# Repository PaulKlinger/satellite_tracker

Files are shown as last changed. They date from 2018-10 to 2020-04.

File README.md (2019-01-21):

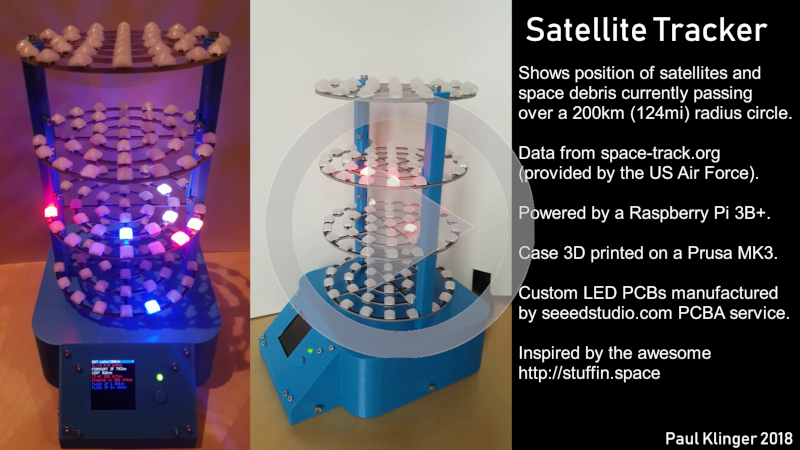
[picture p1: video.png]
(http://www.youtube.com/watch?v=Xof4bjcwHAY "Project video")


This is the code and hardware design for my
[Satellite tracker](https://www.reddit.com/r/space/comments/9py5qd/i_made_a_thingy_that_shows_satellites_and_space/).

The orbit_np.py file is a modified version of [pyorbital](https://github.com/pytroll/pyorbital)
(it calculates the orbits of all the satellites at the same time to increase performance).

Requires https://github.com/PaulKlinger/LIBtft144 and https://github.com/jgarff/rpi_ws281x + a bunch of libraries from PyPi.

The PCB design for the LED boards is in the PCBs/LED folder. I've reversed the VCC/GND connections on one side of the pcb
compared to my version to make assembly easier. Files for three additional PCBs connecting the various parts are in the
PCB/auxiliary folder (these are not strictly necessary, I just used protoboard for the first version).

The STLs and Fusion 360 source for the 3d printed parts are in the "3D printed parts" folder.
Note that the 3d printer files are for a slightly earlier version of the auxiliary PCBs, which still had some issues.
So the current ones probably don't fit exactly, e.g. the display cutout might be slightly offset.

I'd strongly recommend that anyone who builds this uses threaded rods through the pillars instead of the million screws
I used. (I just didn't have any rods and wanted to build it right away.)

The 3 PCBs in the PCBs/auxiliary folder include:
* One which splits the incoming micro usb power between the RaspberryPi and the LED boards.
Contains a micro usb port, a 1000uf capacitor, a right angle micro usb coord to connect to the Pi, and a connector
(LED strip type) to connect power to the led boards.
* A header board which plugs into the Pi. Contains a 2*20 pin header, a SN74AHCT125N level shifter,
and a 4 pin and 10 pin "JST 1.25mm" connector (that's what they are called on aliexpress at least).
* And an interface board with a standard (6x6mm) push button, a 470 ohm resistor, a 3mm LED,
and the 1.44" tft (with ST7735 driver chip)

These 3 PCBs are combined onto one ~10*10cm panel. Many PCB manufacturers charge extra for panelized designs but
[dirtypcbs](https://dirtypcbs.com) doesn't.

The designs here fix some errors of the ones that I ordered. Assembled mine look like this:
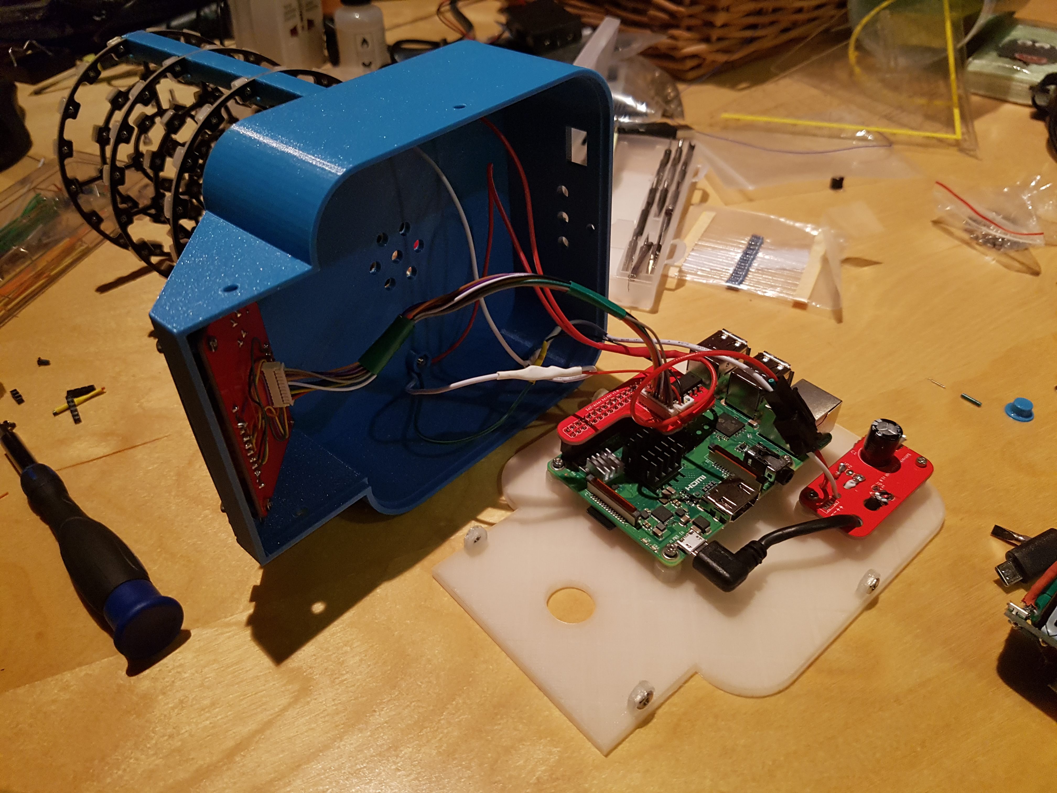
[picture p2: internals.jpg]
Sattracker internals


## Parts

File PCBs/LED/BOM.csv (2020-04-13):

Designator | Manufacturer Part Number | Quantity
C1,C2,C3,C4,C5,C6,C7,C8,C9,C10,C11,C12,C13,C14,C15,C16,C17,C18,C19,C20,C21,C22,C23,C24,C25,C26,C27,C28,C29,C30,C31,C32,C33,C34,C35,C36,C37 | CC0805KRX7R9BB104 | 37
L | WS2812B | 37

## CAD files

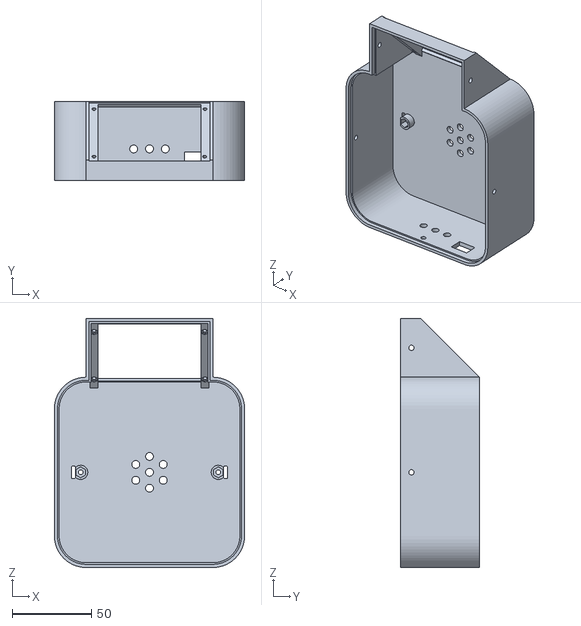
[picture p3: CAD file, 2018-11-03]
3D printed parts/case.stl
120.0 x 50.0 x 157.0

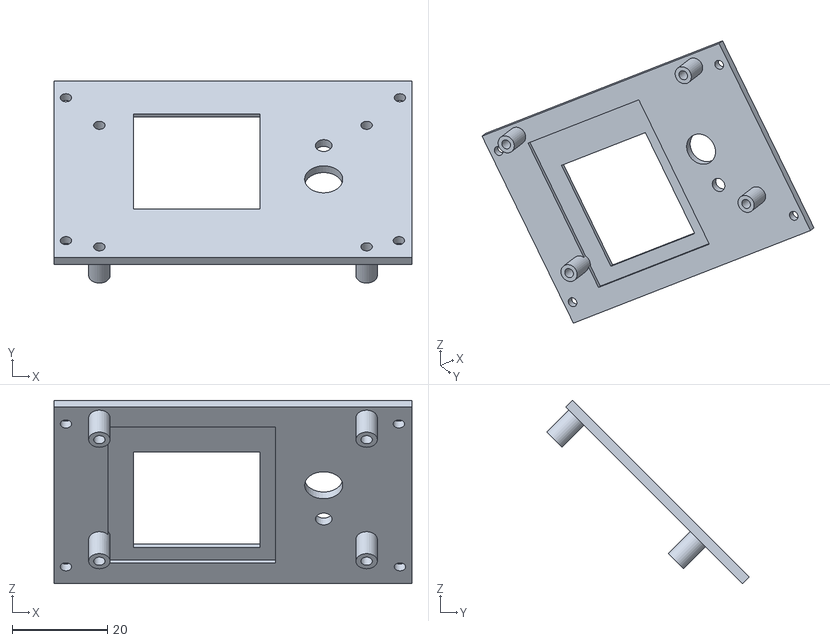
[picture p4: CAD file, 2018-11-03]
3D printed parts/interface plate.stl
75.0 x 42.4 x 38.4

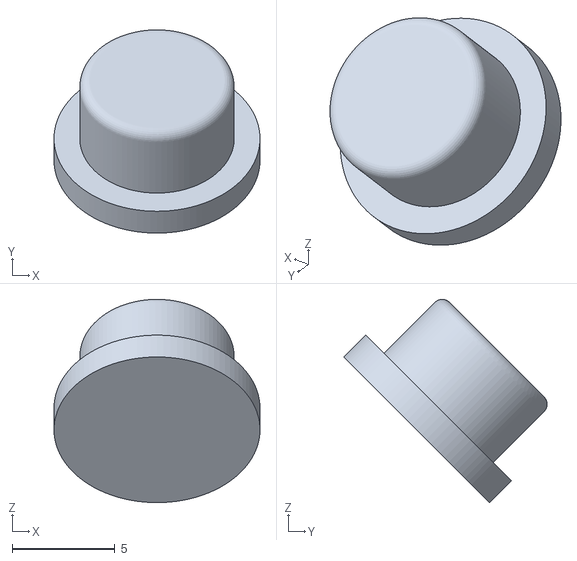
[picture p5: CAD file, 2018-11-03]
3D printed parts/Button.stl
10.0 x 9.87 x 9.87

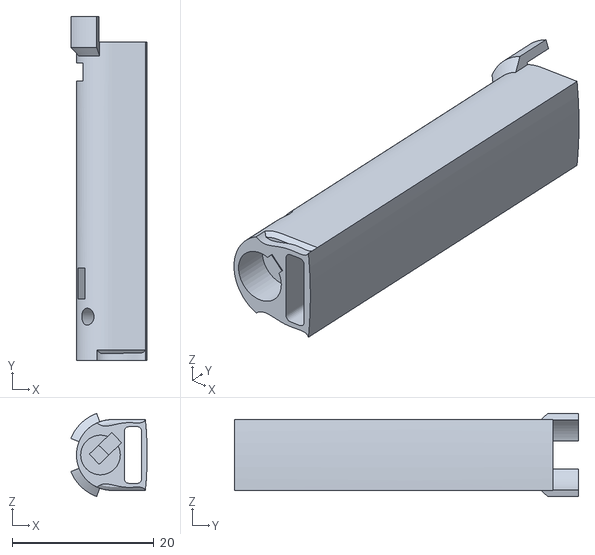
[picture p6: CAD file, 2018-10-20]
3D printed parts/top_pillar.stl
10.8 x 48.6 x 11.7

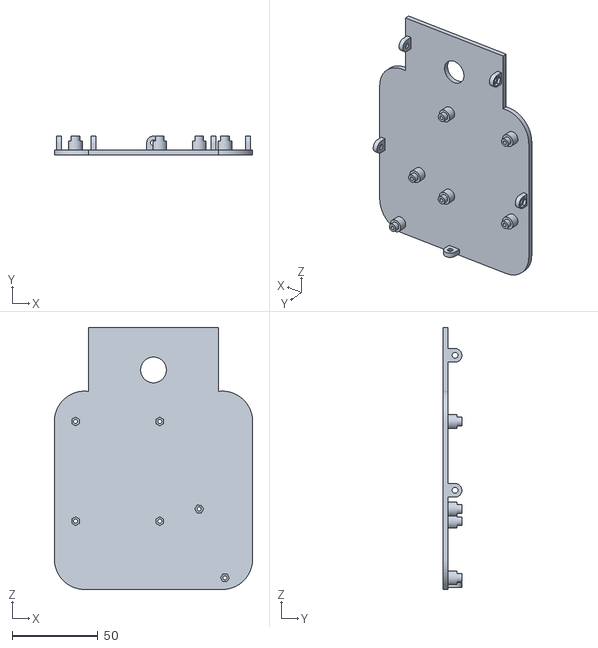
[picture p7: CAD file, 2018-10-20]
3D printed parts/bottom.stl
115.4 x 11.0 x 152.4

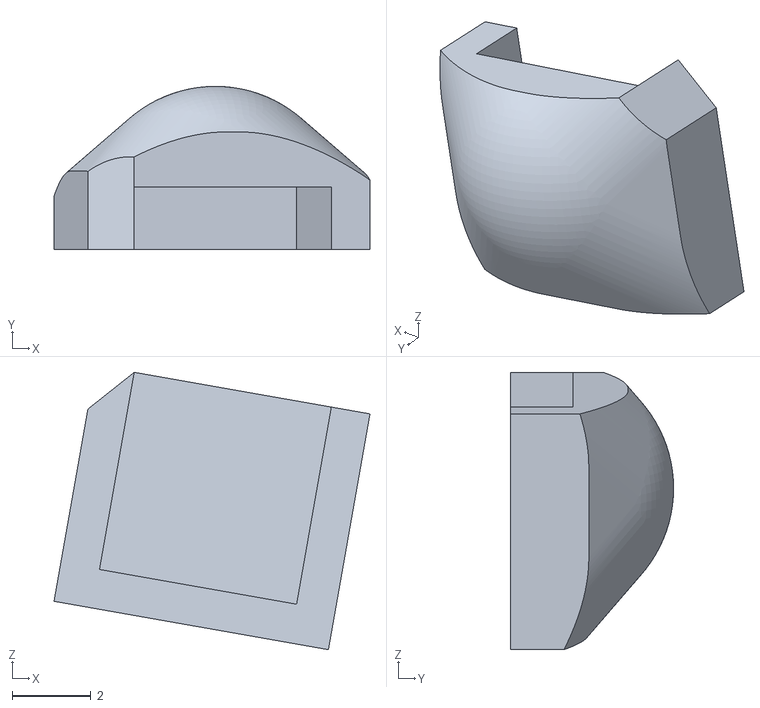
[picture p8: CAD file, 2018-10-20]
3D printed parts/diffuser_round_right.stl
8.05 x 4.16 x 7.07

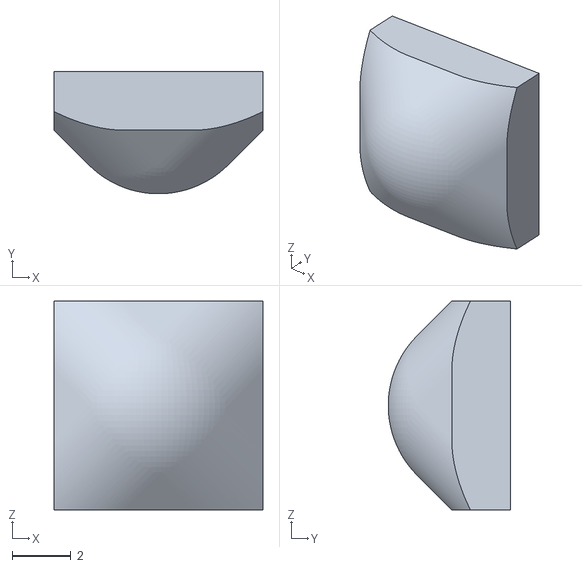
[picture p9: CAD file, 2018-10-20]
3D printed parts/diffuser_round.stl
7.10 x 4.16 x 7.10

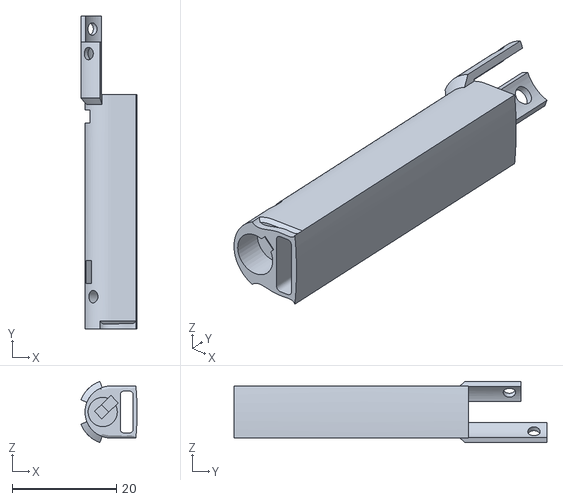
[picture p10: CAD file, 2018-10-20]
3D printed parts/middle_pillar.stl
10.8 x 60.0 x 11.7

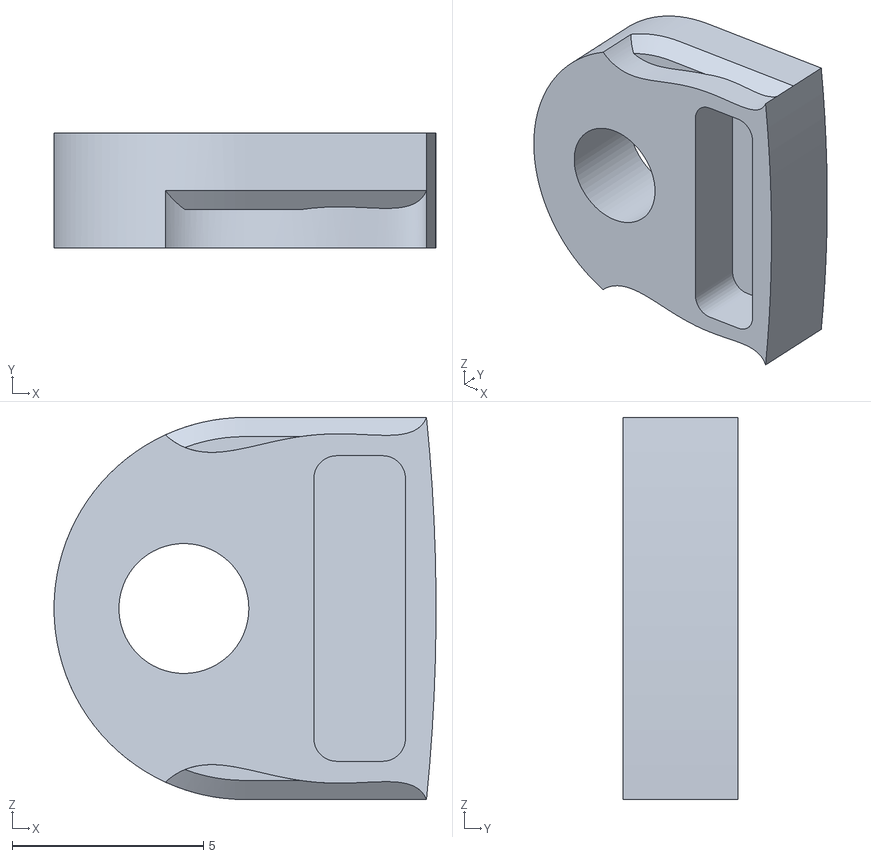
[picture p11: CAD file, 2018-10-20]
3D printed parts/top_cover.stl
10.00 x 3.00 x 10.00

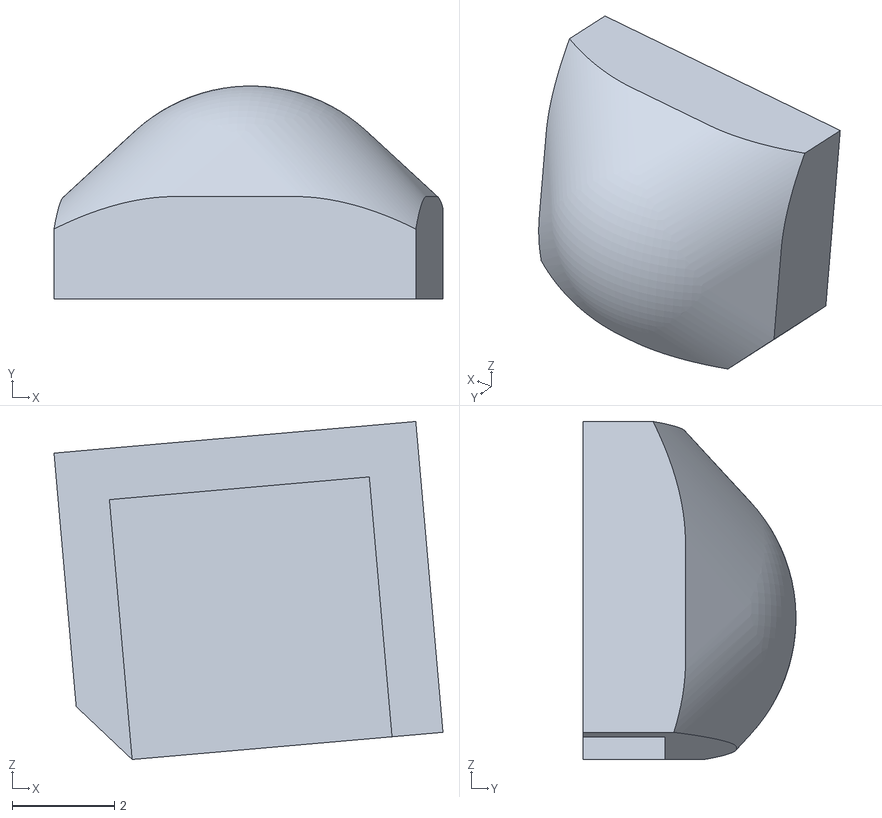
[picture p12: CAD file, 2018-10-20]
3D printed parts/diffuser_round_left.stl
7.60 x 4.16 x 6.61

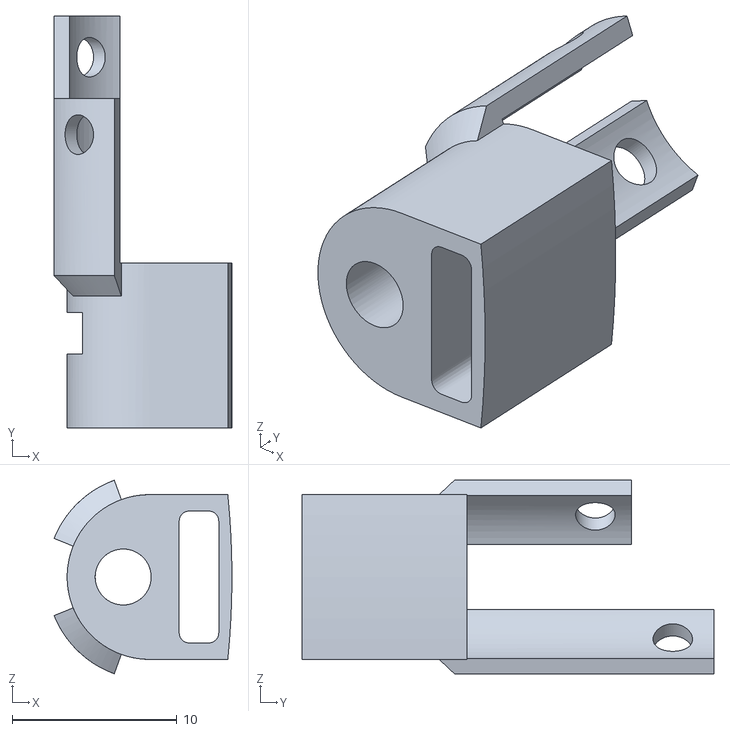
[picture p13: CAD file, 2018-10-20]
3D printed parts/bottom_pillar.stl
10.8 x 25.0 x 11.7

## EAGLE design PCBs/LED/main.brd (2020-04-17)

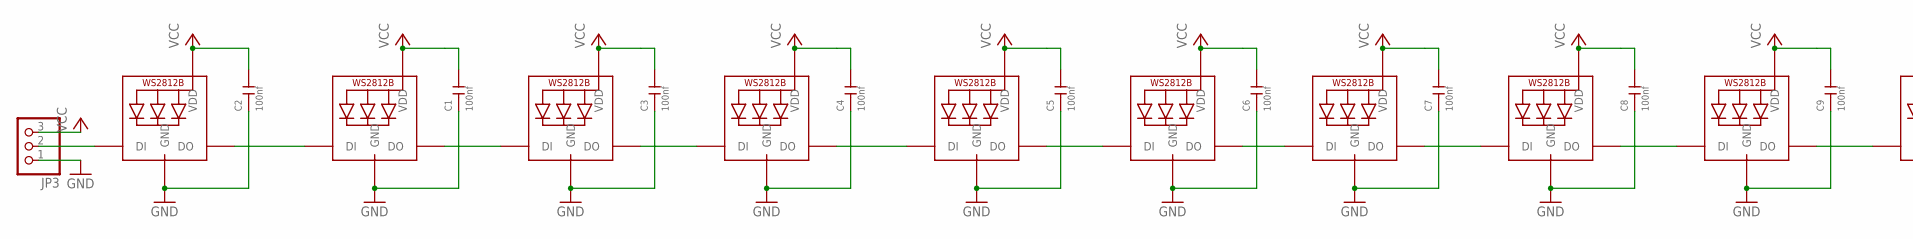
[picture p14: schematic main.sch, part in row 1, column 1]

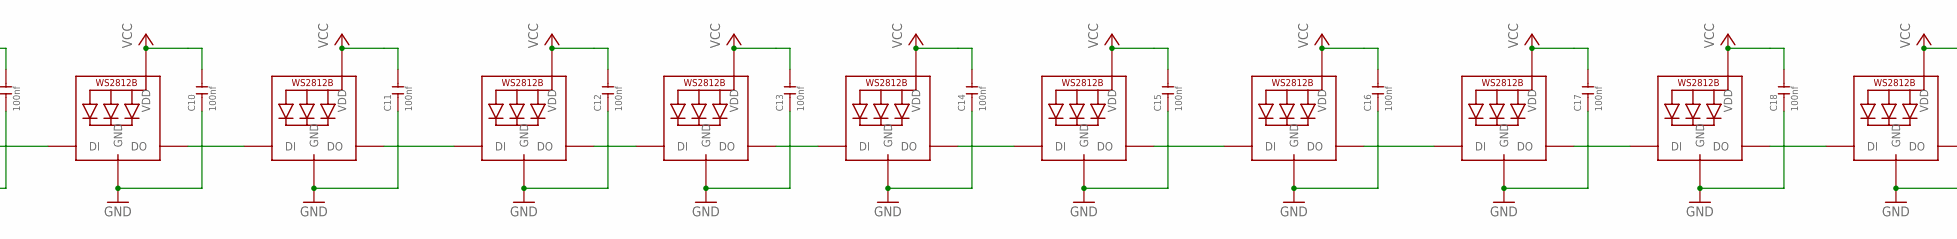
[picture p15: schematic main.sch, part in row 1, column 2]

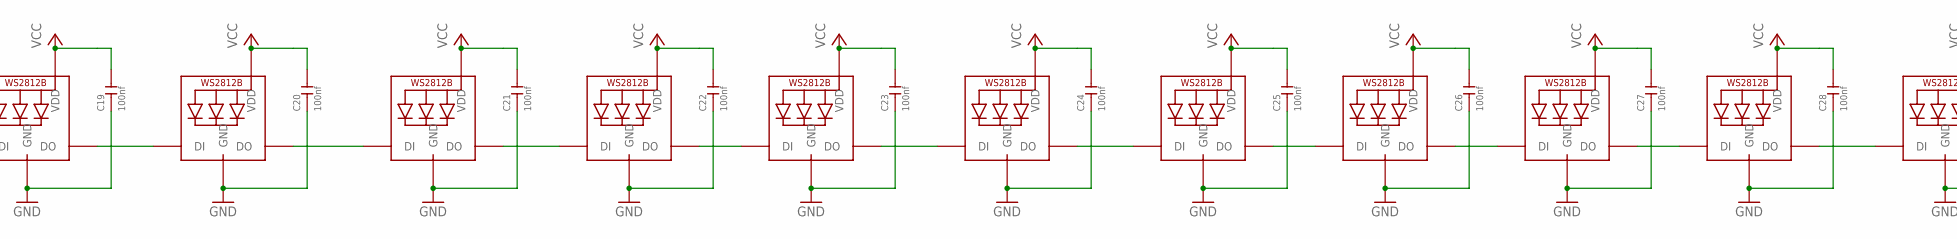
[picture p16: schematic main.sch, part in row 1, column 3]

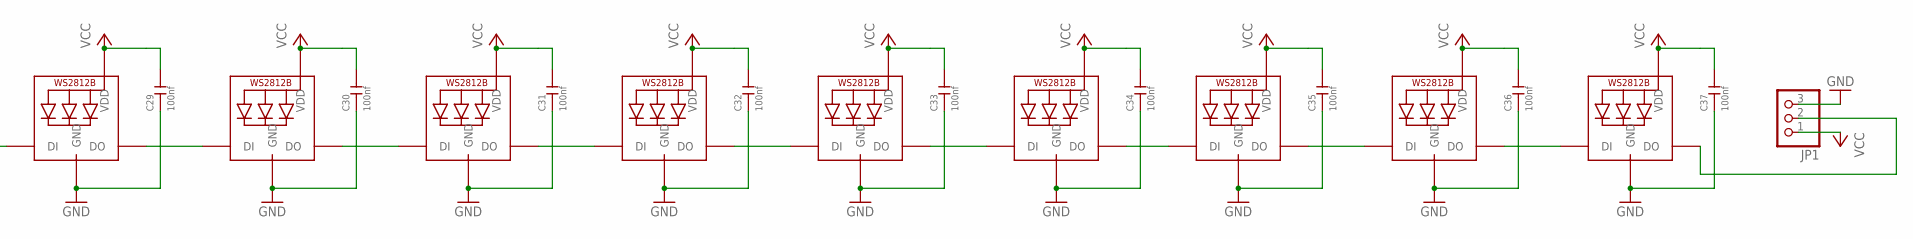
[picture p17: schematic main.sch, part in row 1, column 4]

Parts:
C1, C2, C3, C4, C5, C6, C7, C8, C9, C10, C11, C12, C13, C14, C15, C16, C17, C18, C19, C20, C21, C22, C23, C24, C25, C26, C27, C28, C29, C30, C31, C32, C33, C34, C35, C36, C37: 100nf; C0805
JP1, JP3: PINHD-1X3; 1X03
L: WS2812B5050; WS2812B
LED1, LED3, LED4, LED5, LED6, LED7, LED8, LED9, LED10, LED11, LED12, LED13, LED14, LED15, LED16, LED17, LED18, LED19, LED20, LED21, LED22, LED23, LED24, LED25, LED26, LED27, LED28, LED29, LED30, LED31, LED32, LED33, LED34, LED35, LED36, LED37: WS2812B5050; WS2812B

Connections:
GND: C1.1, C2.1, C3.1, C4.1, C5.1, C6.1, C7.1, C8.1, C9.1, C10.1, C11.1, C12.1, C13.1, C14.1, C15.1, C16.1, C17.1, C18.1, C19.1, C20.1, C21.1, C22.1, C23.1, C24.1, C25.1, C26.1, C27.1, C28.1, C29.1, C30.1, C31.1, C32.1, C33.1, C34.1, C35.1, C36.1, C37.1, JP1.3, JP3.1, L.3-GND (GND), LED1.3-GND (GND), LED3.3-GND (GND), LED4.3-GND (GND), LED5.3-GND (GND), LED6.3-GND (GND), LED7.3-GND (GND), LED8.3-GND (GND), LED9.3-GND (GND), LED10.3-GND (GND), LED11.3-GND (GND), LED12.3-GND (GND), LED13.3-GND (GND), LED14.3-GND (GND), LED15.3-GND (GND), LED16.3-GND (GND), LED17.3-GND (GND), LED18.3-GND (GND), LED19.3-GND (GND), LED20.3-GND (GND), LED21.3-GND (GND), LED22.3-GND (GND), LED23.3-GND (GND), LED24.3-GND (GND), LED25.3-GND (GND), LED26.3-GND (GND), LED27.3-GND (GND), LED28.3-GND (GND), LED29.3-GND (GND), LED30.3-GND (GND), LED31.3-GND (GND), LED32.3-GND (GND), LED33.3-GND (GND), LED34.3-GND (GND), LED35.3-GND (GND), LED36.3-GND (GND), LED37.3-GND (GND)
unnamed: L.2-DOUT (DO), LED1.4-DIN (DI)
unnamed: LED1.2-DOUT (DO), LED3.4-DIN (DI)
unnamed: LED3.2-DOUT (DO), LED4.4-DIN (DI)
unnamed: LED4.2-DOUT (DO), LED5.4-DIN (DI)
unnamed: LED5.2-DOUT (DO), LED6.4-DIN (DI)
unnamed: LED6.2-DOUT (DO), LED7.4-DIN (DI)
unnamed: LED7.2-DOUT (DO), LED8.4-DIN (DI)
unnamed: LED8.2-DOUT (DO), LED9.4-DIN (DI)
unnamed: LED9.2-DOUT (DO), LED10.4-DIN (DI)
unnamed: LED10.2-DOUT (DO), LED11.4-DIN (DI)
unnamed: LED11.2-DOUT (DO), LED12.4-DIN (DI)
unnamed: LED12.2-DOUT (DO), LED13.4-DIN (DI)
unnamed: LED13.2-DOUT (DO), LED14.4-DIN (DI)
unnamed: LED14.2-DOUT (DO), LED15.4-DIN (DI)
unnamed: LED15.2-DOUT (DO), LED16.4-DIN (DI)
unnamed: LED16.2-DOUT (DO), LED17.4-DIN (DI)
unnamed: LED17.2-DOUT (DO), LED18.4-DIN (DI)
unnamed: LED18.2-DOUT (DO), LED19.4-DIN (DI)
unnamed: LED19.2-DOUT (DO), LED20.4-DIN (DI)
unnamed: LED20.2-DOUT (DO), LED21.4-DIN (DI)
unnamed: LED21.2-DOUT (DO), LED22.4-DIN (DI)
unnamed: LED22.2-DOUT (DO), LED23.4-DIN (DI)
unnamed: LED23.2-DOUT (DO), LED24.4-DIN (DI)
unnamed: LED24.2-DOUT (DO), LED25.4-DIN (DI)
unnamed: LED25.2-DOUT (DO), LED26.4-DIN (DI)
unnamed: LED26.2-DOUT (DO), LED27.4-DIN (DI)
unnamed: LED27.2-DOUT (DO), LED28.4-DIN (DI)
unnamed: LED28.2-DOUT (DO), LED29.4-DIN (DI)
unnamed: LED29.2-DOUT (DO), LED30.4-DIN (DI)
unnamed: LED30.2-DOUT (DO), LED31.4-DIN (DI)
unnamed: LED31.2-DOUT (DO), LED32.4-DIN (DI)
unnamed: LED32.2-DOUT (DO), LED33.4-DIN (DI)
unnamed: LED33.2-DOUT (DO), LED34.4-DIN (DI)
unnamed: LED34.2-DOUT (DO), LED35.4-DIN (DI)
unnamed: LED35.2-DOUT (DO), LED36.4-DIN (DI)
unnamed: LED36.2-DOUT (DO), LED37.4-DIN (DI)
unnamed: JP3.2, L.4-DIN (DI)
unnamed: JP1.2, LED37.2-DOUT (DO)
VCC: C1.2, C2.2, C3.2, C4.2, C5.2, C6.2, C7.2, C8.2, C9.2, C10.2, C11.2, C12.2, C13.2, C14.2, C15.2, C16.2, C17.2, C18.2, C19.2, C20.2, C21.2, C22.2, C23.2, C24.2, C25.2, C26.2, C27.2, C28.2, C29.2, C30.2, C31.2, C32.2, C33.2, C34.2, C35.2, C36.2, C37.2, JP1.1, JP3.3, L.1-VDD (VDD), LED1.1-VDD (VDD), LED3.1-VDD (VDD), LED4.1-VDD (VDD), LED5.1-VDD (VDD), LED6.1-VDD (VDD), LED7.1-VDD (VDD), LED8.1-VDD (VDD), LED9.1-VDD (VDD), LED10.1-VDD (VDD), LED11.1-VDD (VDD), LED12.1-VDD (VDD), LED13.1-VDD (VDD), LED14.1-VDD (VDD), LED15.1-VDD (VDD), LED16.1-VDD (VDD), LED17.1-VDD (VDD), LED18.1-VDD (VDD), LED19.1-VDD (VDD), LED20.1-VDD (VDD), LED21.1-VDD (VDD), LED22.1-VDD (VDD), LED23.1-VDD (VDD), LED24.1-VDD (VDD), LED25.1-VDD (VDD), LED26.1-VDD (VDD), LED27.1-VDD (VDD), LED28.1-VDD (VDD), LED29.1-VDD (VDD), LED30.1-VDD (VDD), LED31.1-VDD (VDD), LED32.1-VDD (VDD), LED33.1-VDD (VDD), LED34.1-VDD (VDD), LED35.1-VDD (VDD), LED36.1-VDD (VDD), LED37.1-VDD (VDD)

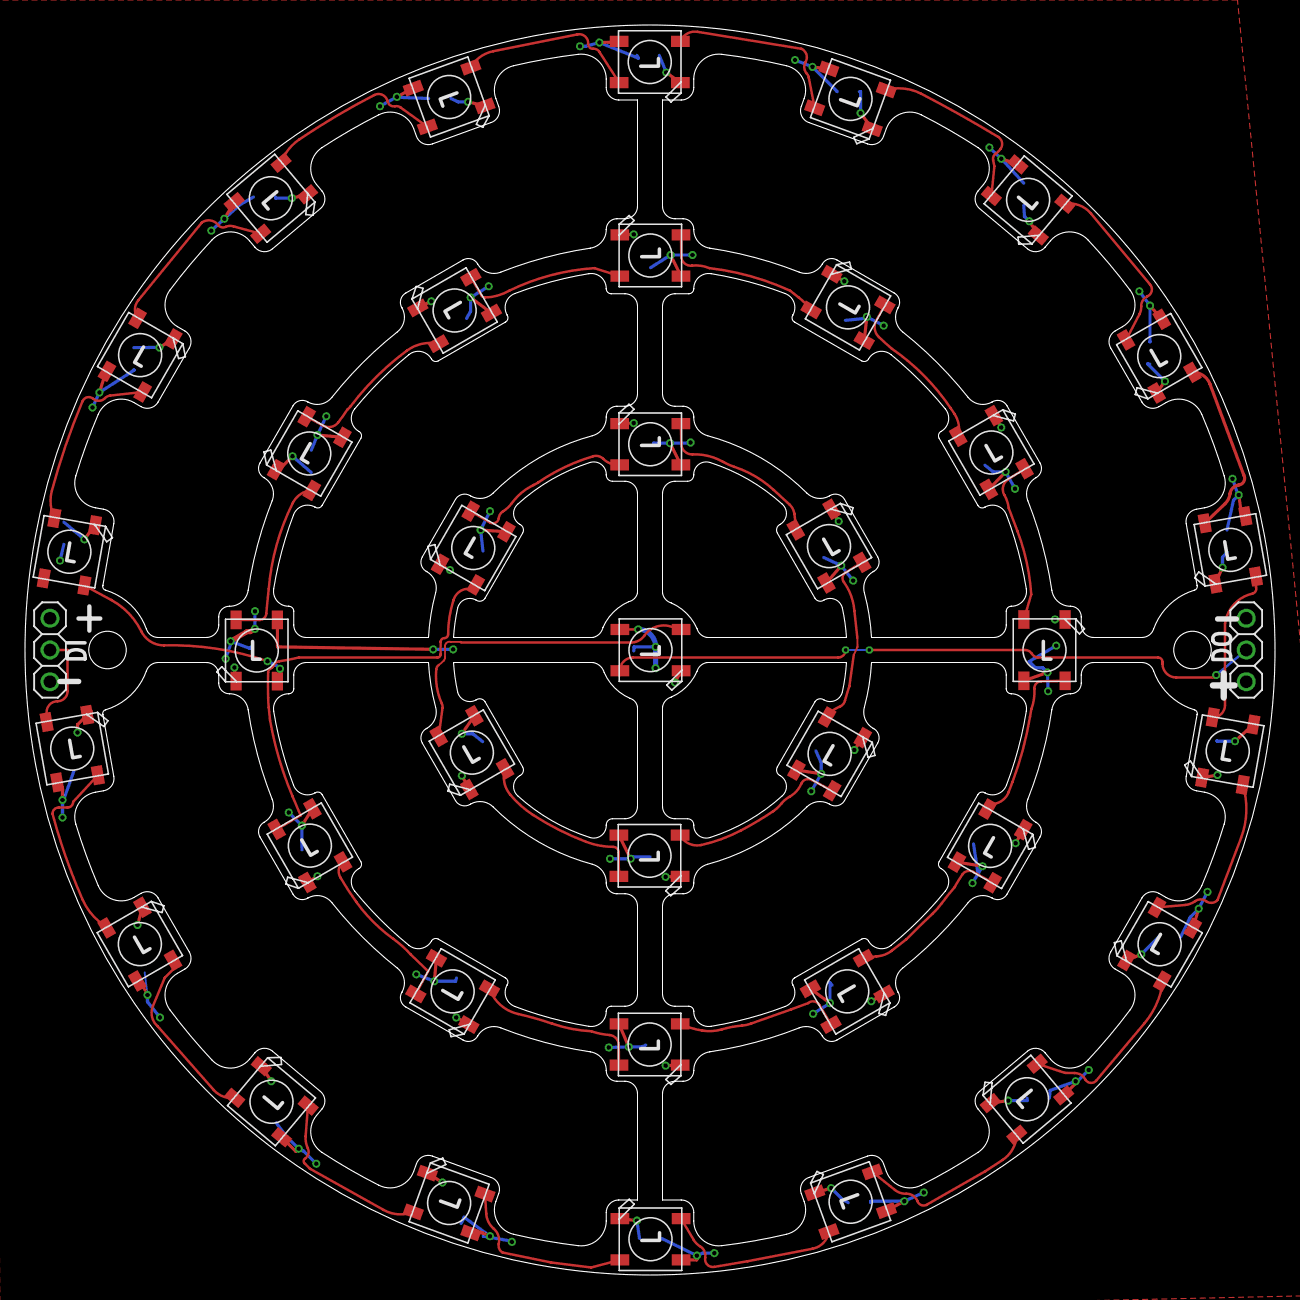
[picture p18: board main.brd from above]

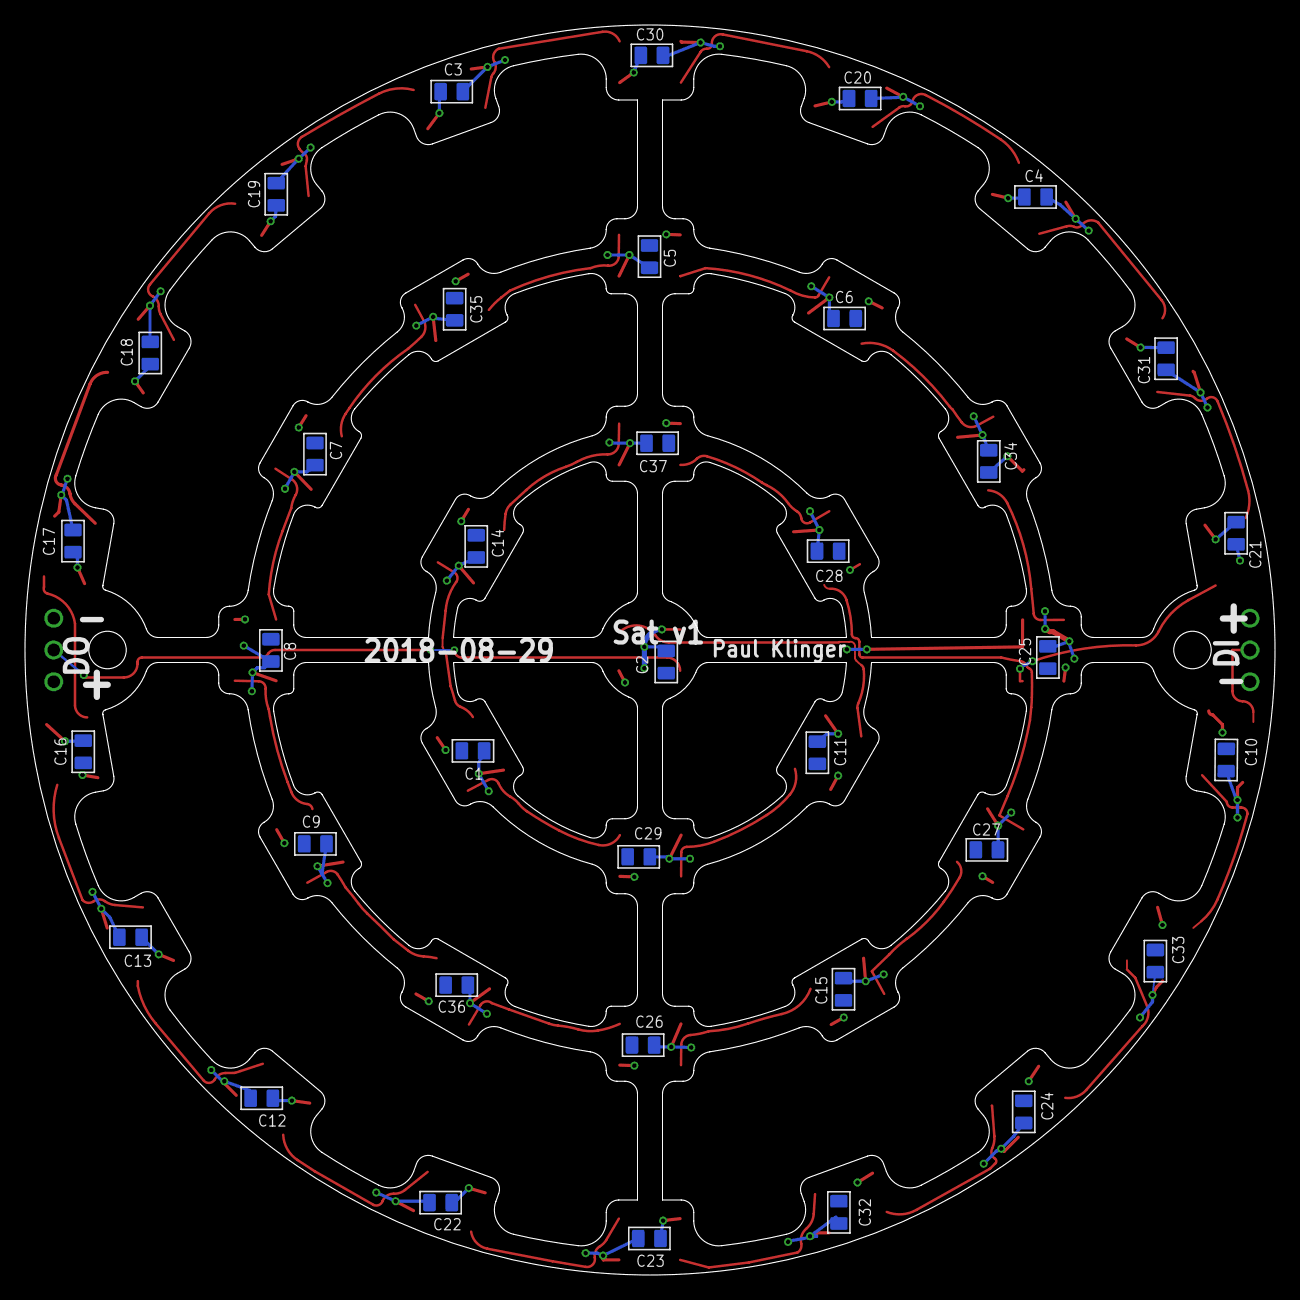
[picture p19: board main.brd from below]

Board: 2 copper layers, 100.0 x 100.0 mm, 76 parts (37 on the bottom side), 40 nets.

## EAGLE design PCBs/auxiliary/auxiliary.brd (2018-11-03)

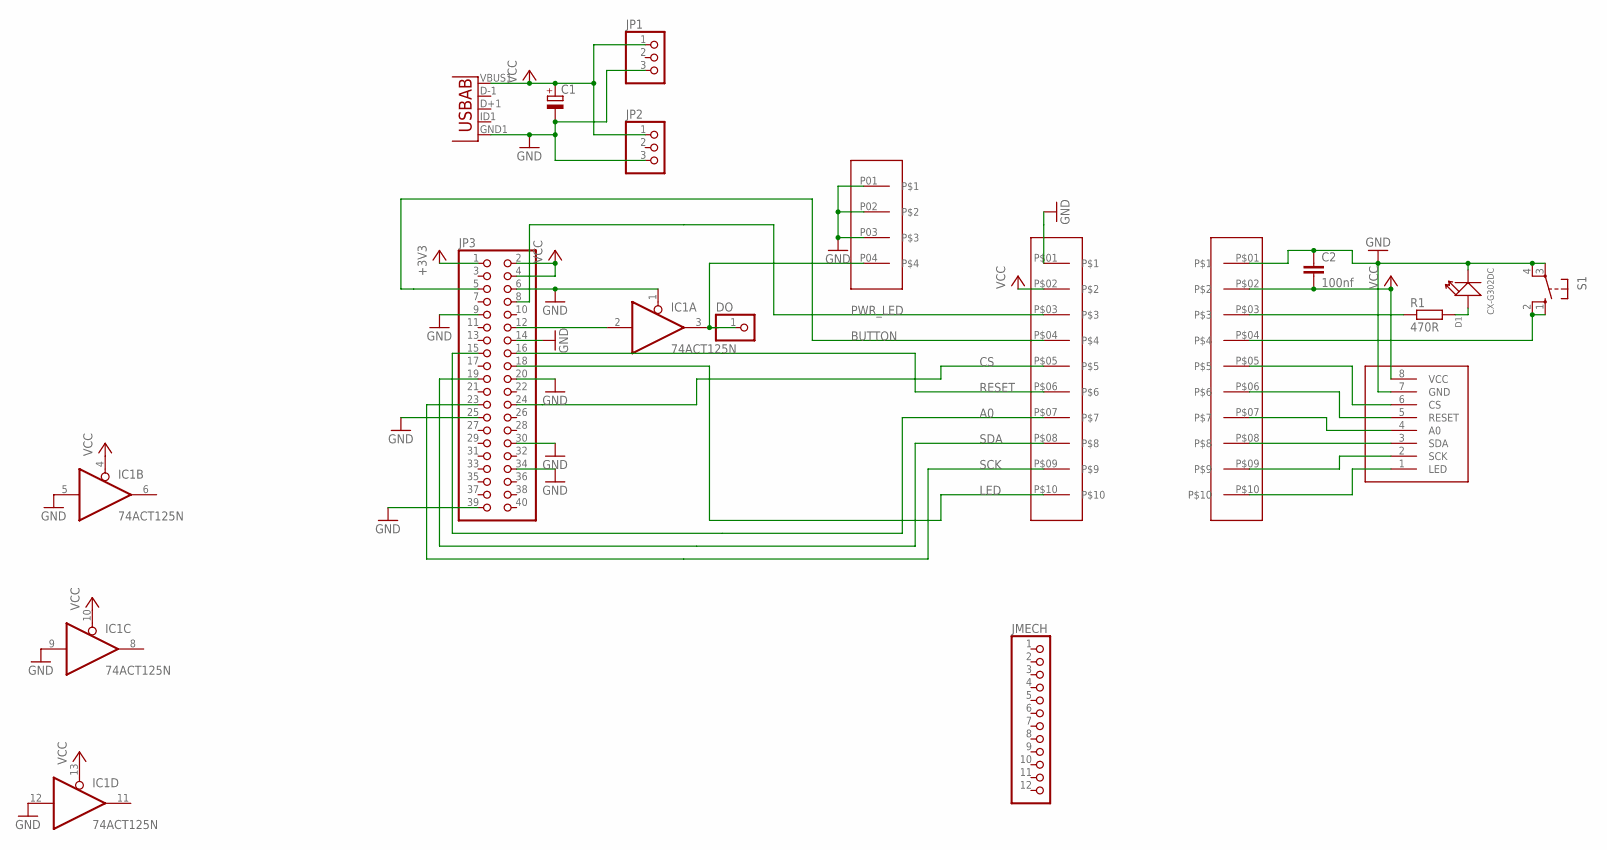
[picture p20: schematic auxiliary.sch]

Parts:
C1: CPOL-EUE5-10.5; E5-10,5
C2: 100nf; C025-030X050
D1: CX-G302DC; LED2-2.54-D3.0MM
DO: PINHD-1X1; 1X01
IC1: 74ACT125N; DIL14
J1, J2: JST1.25_10PIN
JMECH: PINHD-1X12; 1X12
JP1, JP2: PINHD-1X3; 1X03
JP3: PINHD-2X20; 2X20
R1: 470R; 0207/7
S1: 10-XX; B3F-10XX
U1: USB-THROUGH; USB-MICRO-THROUGH
U$2: SPI_TFT_1.44"
U$3: JST1.25_4PIN

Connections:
+3V3: JP3.1
A0: J1.P$07, JP3.15
BUTTON: J1.P$04, JP3.5
CS: J1.P$05, JP3.24
GND: C1.-, C2.1, D1.K (-), IC1.1 (OE), IC1.5 (I), IC1.7 (GND), IC1.9 (I), IC1.12 (I), J1.P$01, J2.P$01, JP1.3, JP2.3, JP3.6, JP3.9, JP3.14, JP3.20, JP3.25, JP3.30, JP3.34, JP3.39, S1.3, S1.4 (P1), U1.GND1 (GND), U$2.7 (GND), U$3.P01, U$3.P02, U$3.P03
LED: J1.P$10, JP3.18
unnamed: D1.A (+), R1.2
unnamed: DO.1, IC1.3 (O), U$3.P04
unnamed: IC1.2 (I), JP3.12
unnamed: J2.P$05, U$2.6 (CS)
unnamed: J2.P$06, U$2.5 (RESET)
unnamed: J2.P$07, U$2.4 (A0)
unnamed: J2.P$08, U$2.3 (SDA)
unnamed: J2.P$09, U$2.2 (SCK)
unnamed: J2.P$03, R1.1
unnamed: J2.P$10, U$2.1 (LED)
unnamed: J2.P$04, S1.1 (S), S1.2 (S1)
PWR_LED: J1.P$03, JP3.8
RESET: J1.P$06, JP3.16
SCK: J1.P$09, JP3.23
SDA: J1.P$08, JP3.19
VCC: C1.+, C2.2, IC1.4 (OE), IC1.10 (OE), IC1.13 (OE), IC1.14 (VCC), J1.P$02, J2.P$02, JP1.1, JP2.1, JP3.2, JP3.4, U1.VBUS1 (VBUS), U$2.8 (VCC)

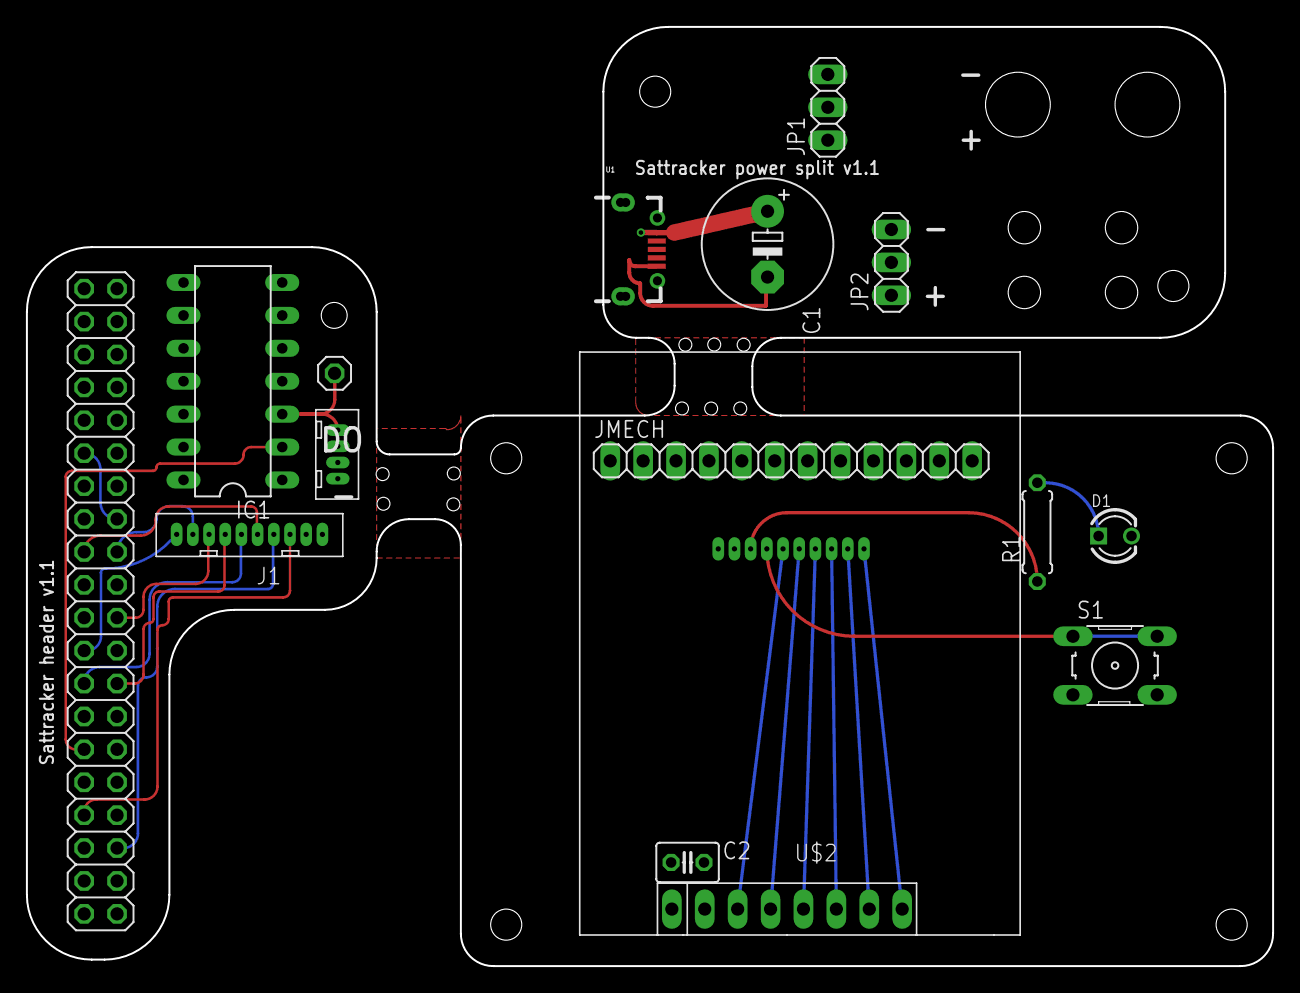
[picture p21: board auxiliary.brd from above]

Board: 2 copper layers, 96.2 x 72.5 mm, 16 parts (1 on the bottom side), 21 nets.

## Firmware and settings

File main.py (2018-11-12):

from datetime import datetime, timedelta
from time import time, sleep
import itertools
import multiprocessing as mp
import subprocess
import queue
from collections import defaultdict
import os
import os.path
from typing import List, Tuple, Optional

from subprocess import check_call

from geopy import distance
import neopixel
from gpiozero import Button
import RPi.GPIO as GPIO
from LIBtft144.lib_tft144 import TFT144
import spidev

from orbit_np import Orbitals
from demo import chase_loop, random_loop, rings_loop, spinning_loop, alternate_loop, half_loop
from constants import *


class NearbySatFinder(object):
    def __init__(self, tlefile: str, loc: Pos):
        self.loc = loc
        self.longfactor = np.cos(np.deg2rad(loc.lat))
        self.tles = []
        satnames = []

        with open(tlefile) as f:
            n = 0
            while True:
                n += 1
                satname = f.readline().strip()
                if not satname:
                    # there should be exactly one empty line at the end of the TLE file
                    # check if we are at the end of the file after reading it
                    if f.read(1) != "":  # at the end file.read returns ""
                        # if we are not at the end, something is wrong -> abort
                        raise ValueError("Unexpected empty line in TLE file!")

                    print("Loaded {} sats.".format(n))
                    break
                line1 = f.readline().strip()
                line2 = f.readline().strip()
                if line1 and line2:
                    self.tles.append((line1, line2))
                    satnames.append(satname)

        self.satnames = np.array(satnames)

        self.last_query_t = -1000

        self.filtered_errors = False
        self.create_orbitals()

    def create_orbitals(self):
        print("creating orbitals")
        self.orbs = Orbitals(self.tles)

    def nearby_now(self) -> List[Tuple[str, Pos, float]]:
        now = datetime.utcnow()

        t1 = time()
        self.last_query_t = t1

        lons, lats, alts, errors = self.orbs.get_lonlatalt(now)
        t2 = time()
        rough_near = np.logical_and(np.abs(lats - self.loc.lat) < 3, np.abs(lons - self.loc.long) < 3)
        valid_satpos = list(
            zip(self.satnames[~errors][rough_near], lats[rough_near], lons[rough_near], alts[rough_near]))
        nearby = [(name, Pos(lat=lat, long=lon), alt) for name, lat, lon, alt in valid_satpos if
                  distance.distance(self.loc, (lat, lon)).km < 200]
        t3 = time()
        print("loc:{:.2f}s dist: {:.2f}s tot: {:.2f}s, sats: {:02d}".format(t2 - t1, t3 - t2, t3 - t1, len(nearby)))

        if not self.filtered_errors:
            print("filtering errors")
            self.satnames = self.satnames[~errors]
            self.tles = itertools.compress(self.tles, ~errors)
            self.create_orbitals()
            self.filtered_errors = True
        return nearby


class LedArray(object):
    def __init__(self, ring_radii, ring_ledns, ring_startangles, ring_dirs, eq_radius, pos: Pos,
                 upper_levels_alt_lower_boundaries):
        self.eq_radius = eq_radius  # equivalent real radius in km
        self.pos = pos
        self.upper_levels_alt_lower_boundaries = upper_levels_alt_lower_boundaries
        self.level_ledn = np.sum(ring_ledns)

        self.longfactor = np.cos(np.deg2rad(self.pos.lat))
        degreelength = 111  # km
        self.levels_led_poss = []
        distance_factor = eq_radius / np.max(ring_radii)
        for level in range(len(upper_levels_alt_lower_boundaries) + 1):
            led_poss = []
            for ringr, ledn, startangle, direction in zip(ring_radii, ring_ledns, ring_startangles, ring_dirs):
                startangle += (level % 2) * np.pi  # upper levels are rotated 180 degree (to connect do/di)
                anglestep = 2 * np.pi / ledn
                led_poss += [
                    Pos(lat=pos.lat - distance_factor * ringr * np.cos(
                        startangle + i * anglestep * direction) / degreelength,
                        long=pos.long + distance_factor * ringr * np.sin(
                            startangle + i * anglestep * direction) / degreelength / self.longfactor
                        ) for i in range(ledn)]
            self.levels_led_poss.append(led_poss)

    def _level_from_alt(self, alt: float) -> int:
        i = 0
        for alt_boundary in self.upper_levels_alt_lower_boundaries:
            if alt < alt_boundary:
                break
            i += 1
        return i

    def closest_led(self, pos: Pos, alt: float) -> Tuple[Pos, int, float]:
        level = self._level_from_alt(alt)
        closest_led_index = None
        closest_led_distance = (2 * self.eq_radius) ** 2
        for i, ledpos in enumerate(self.levels_led_poss[level]):
            # naive distance calculation, accurate enough for the inter-led distances
            d = ((ledpos.long - pos.long) * self.longfactor) ** 2 + (ledpos.lat - pos.lat) ** 2
            if d < closest_led_distance:
                closest_led_distance = d
                closest_led_index = i

        closest_led_pos = self.levels_led_poss[level][closest_led_index]
        closest_led_index += level * self.level_ledn
        return closest_led_pos, closest_led_index, closest_led_distance


def led_array_from_constants():
    # convenience function
    return LedArray(ring_radii=RING_RADII, ring_ledns=RING_LEDNS, ring_startangles=RING_STARTANGLES,
                    ring_dirs=RING_DIRECTIONS, eq_radius=EQUIV_RADIUS, pos=CENTER_LOCATION,
                    upper_levels_alt_lower_boundaries=UPPER_LEVELS_ALT_LOWER_BOUNDARIES)


def color_priority_from_name(name: str) -> Tuple[RGB, int, RGB]:
    for c, tftc_prio_ledc in CLASS_COLORS_PRIORITIES:
        if any(s in name for s in c):
            return tftc_prio_ledc


def run_demo(strip: neopixel.Adafruit_NeoPixel, led_queue: mp.Queue):
    for demo in (chase_loop, spinning_loop, rings_loop, random_loop):
        print("demo: {}".format(demo))
        p = mp.Process(target=demo, kwargs={"strip": strip, })
        p.start()
        sleep(5)  # show each demo for 5s
        while True:
            # get messages, ignore satellite updates that might still be in the queue
            try:
                m = led_queue.get_nowait()
                if m == "BUTTON":  # if the button is pressed we stay in the demo
                    while True:
                        m = led_queue.get()
                        if m == "BUTTON":  # if the button is pressed again we exit
                            p.terminate()
                            return
            except queue.Empty:
                # if there was no button press move on to the next demo
                p.terminate()
                break


def led_strip_from_constants():
    return neopixel.Adafruit_NeoPixel(LED_COUNT, LED_PIN, LED_FREQ_HZ, LED_DMA,
                                      LED_INVERT, LED_BRIGHTNESS, LED_CHANNEL,
                                      strip_type=neopixel.ws.WS2811_STRIP_GRB)


def led_control(led_queue: mp.Queue, demo_mode: mp.Lock):
    strip = led_strip_from_constants()

    # Intialize the library (must be called once before other functions).
    strip.begin()

    def set_all(strip, color):
        for i in range(strip.numPixels()):
            strip.setPixelColor(i, color)
        strip.show()

    set_all(strip, neopixel.Color(0, 0, 0))

    current = defaultdict(lambda: RGB(0, 0, 0))  # TODO: add variable type hints once Raspbian includes Python >=3.6
    target = defaultdict(lambda: RGB(0, 0, 0))
    step = defaultdict(lambda: RGB(0, 0, 0))
    loading_anim_process = mp.Process(target=half_loop, args=(strip,))
    loading_anim_process.start()
    m = led_queue.get()
    loading_anim_process.terminate()
    led_queue.put(m)  # ugly...

    while True:
        t0 = time()
        try:
            message = led_queue.get_nowait()
        except queue.Empty:
            pass
        else:
            if message == "DEMO":
                print("got demo message")
                demo_mode.acquire()
                print("acquired demo lock")
                run_demo(strip, led_queue)
                demo_mode.release()
                continue
            elif message == "BUTTON":
                # pressed the button too late to stay in demo mode, just ignore
                continue

            elif message is None:
                set_all(strip, neopixel.Color(0, 0, 0))
                sleep(0.5)
                break
            for i in range(strip.numPixels()):
                newtarget = message[i][1] if i in message else (0, 0, 0)
                if target[i] != newtarget:
                    target[i] = newtarget
                    step[i] = tuple((t - c) / (LED_SWITCH_TIME / LED_STEP_TIME) for t, c in zip(target[i], current[i]))

        for i in range(strip.numPixels()):
            current[i] = tuple(c + s for c, s in zip(current[i], step[i]))
            if any((s < 0 and c < t) or (s > 0 and c > t) for s, c, t in zip(step[i], current[i], target[i])):
                step[i] = (0, 0, 0)
                current[i] = target[i]
            color_int = tuple(int(round(c)) for c in current[i])

            # cut off at low intensity to remove perceived flicker
            # using gamma correction would be better maybe?
            color_int = tuple(0 if c < 10 and s < 0 else c for c, s in zip(color_int, step[i]))
            strip.setPixelColor(i, neopixel.Color(*color_int))

        strip.show()
        t1 = time()
        if t1 - t0 < LED_STEP_TIME:
            sleep(LED_STEP_TIME - (t1 - t0))


def update_tle_file() -> datetime:
    tmp_filename = TLE_FILENAME + "_tmp"
    subprocess.run(
        "curl {} > {}".format(SPACETRACK_URL, tmp_filename),
        shell=True)
    with open(tmp_filename, encoding="utf-8") as f:
        non_empty_line_count = sum(1 for l in f if l.strip())

    # just some heuristics to check if the file is valid
    if non_empty_line_count > 30000 and non_empty_line_count % 3 == 0:
        # (probably) valid, overwrite old file and set last update time to current time
        os.rename(tmp_filename, TLE_FILENAME)
        return datetime.now()
    else:
        # invalid, try again in 10 minutes
        return datetime.now() - timedelta(hours=23, minutes=50)


class SattrackerTFT(object):
    num_lines = 13
    num_chars = int(128 / 6)

    BLACK = RGB(0, 0, 0)
    WHITE = RGB(255, 255, 255)
    BLUE = RGB(0, 0, 255)

    def __init__(self):
        GPIO.setwarnings(False)
        GPIO.setmode(GPIO.BCM)

        self._tft = TFT144(GPIO, spidev.SpiDev(), TFT_CE, TFT_DC, TFT_RST, TFT_LED, board_type=TFT144.NEW_RED_BOARD,
                           orientation=TFT144.ORIENTATION180, spi_speed=16000000)

        self._prev_lines = self.num_lines * [(None, None, None)]

    def write_message(self, message: str):
        self.clear()
        self._tft.put_string(message, 0, 0, self._tft.WHITE, self._tft.BLACK, font=3)
        self._prev_lines = self.num_lines * [(None, None, None)]

    def clear(self, color: Optional[RGB] = None):
        if color is None:
            color = self._tft.BLACK
        self._tft.clear_display(color)

    def write_lines(self, lines: List[Tuple[str, RGB, RGB]]):
        lines += (self.num_lines - len(lines)) * [(" " * self.num_chars, self.BLACK, self.BLACK)]
        dy = 0
        for ((new_text, new_colorfg, new_colorbg),
             (prev_text, prev_colorfg, prev_colorbg)) in zip(lines, self._prev_lines):

            if new_text != prev_text or new_colorfg != prev_colorfg or new_colorbg != prev_colorbg:
                self._tft.put_chars(new_text, 0, dy,
                                    self._tft.colour565(*new_colorfg),
                                    self._tft.colour565(*new_colorbg))  # std font 3 (default)
            dy += 10

        self._prev_lines = lines


class SatTracker(object):
    def __init__(self):
        self.led_queue = mp.Queue()
        self.demo_mode = mp.Lock()

        self.led_process = mp.Process(target=led_control, args=(self.led_queue, self.demo_mode,))

        self.shutting_down = False
        self.last_button_release = 0
        self.show_end_of_lines = False

        # The button has multiple functions:
        # Turn the device on when off, single press to show the end of long lines on the display,
        # double press to start demo mode, single press to stay at one animation in demo mode,
        # long press to shut down
        self.button = Button(3, hold_time=2, bounce_time=0.05)
        self.button.when_held = self.shutdown
        self.button.when_released = self.button_pressed

        self.tft = SattrackerTFT()

        self.tle_updated_time = None

        self.tracker = None  # load in start because it takes quite a long time

        self.led_array = led_array_from_constants()

    def start(self):
        self.led_process.start()
        self.tft.clear()

        if (not os.path.isfile(TLE_FILENAME)) or \
                (datetime.now() - datetime.fromtimestamp(os.path.getmtime(TLE_FILENAME))) > timedelta(days=1):
            self.tft.write_message("Downloading TLEs")
            update_tle_file()
        self.tle_updated_time = datetime.fromtimestamp(os.path.getmtime(TLE_FILENAME))

        self.tft.write_message("Loading Satellites")
        self.tracker = NearbySatFinder(TLE_FILENAME, CENTER_LOCATION)
        self.tracker.nearby_now()  # run once to remove errors

        self.loop()

    def loop(self):
        oddstep = False
        while True:
            if not self.demo_mode.acquire(block=False):
                self.tft.write_message("Showing off :D")
                self.demo_mode.acquire()
            self.demo_mode.release()

            step_start_time = time()

            self.check_tle_update()

            nearby_sats = self.tracker.nearby_now()

            tft_priority_lines = []
            active_leds = {}
            for name, pos, alt in nearby_sats:
                _, led_id, _ = self.led_array.closest_led(pos, alt)
                tft_color, priority, led_color = color_priority_from_name(name)
                if (led_id not in active_leds) or priority > active_leds[led_id][0]:
                    active_leds[led_id] = (priority, led_color)
                line = name[2:] + " {}km".format(int(round(alt)))
                if self.show_end_of_lines:
                    line = line[-21:]
                line = line[:21] + max(21 - len(line), 0) * " "  # trim to display length and pad
                tft_priority_lines.append((priority, (line, tft_color, self.tft.BLACK)))

            tft_priority_lines.sort(key=lambda l: l[0], reverse=True)
            tft_lines = ([("{:03d} sats<{}km      {}".format(len(nearby_sats), EQUIV_RADIUS, "-" if oddstep else "|"),
                         self.tft.WHITE, self.tft.BLUE)]
                         + [l[1] for l in tft_priority_lines])

            if self.show_end_of_lines and time() - self.last_button_release > 2:
                self.show_end_of_lines = False
            if self.shutting_down:
                break
            self.led_queue.put_nowait(active_leds)

            self.tft.write_lines(tft_lines)

            oddstep = not oddstep

            step_time = time() - step_start_time
            print("step_time: {:.2f}s".format(step_time))
            if step_time < TARGET_STEP_TIME:
                sleep(TARGET_STEP_TIME - step_time)

    def check_tle_update(self):
        if datetime.now() - self.tle_updated_time > timedelta(days=1):
            self.tft.write_message("Downloading TLEs")
            self.tle_updated_time = update_tle_file()
            self.tft.write_message("Loading Satellites")
            self.tracker = NearbySatFinder("3le.txt", CENTER_LOCATION)
            self.tracker.nearby_now()  # run once to remove errors

    def shutdown(self):
        self.shutting_down = True
        self.led_queue.put_nowait(None)
        sleep(0.5)
        self.tft.write_message("Shutting down...")
        sleep(0.5)
        check_call(['sudo', 'poweroff'])
        sleep(10)

    def button_pressed(self):
        if time() - self.last_button_release < 1:
            self.led_queue.put_nowait("DEMO")
        else:
            if not self.demo_mode.acquire(block=False):
                self.led_queue.put("BUTTON")
            else:
                self.demo_mode.release()
                self.show_end_of_lines = True
                self.last_button_release = time()


if __name__ == "__main__":
    sat_tracker = SatTracker()
    sat_tracker.start()

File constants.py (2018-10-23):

from collections import namedtuple
import numpy as np

from credentials import SPACETRACK_PASSWD, SPACETRACK_USER

Pos = namedtuple("Pos", "lat long")
RGB = namedtuple("RGB", "r g b")

# Constants determining device behavior
CENTER_LOCATION = Pos(lat=48.224708, long=16.438082)
TARGET_STEP_TIME = 0.5  # s target delta-t between sat position updates
EQUIV_RADIUS = 200  # km
LED_STEP_TIME = 1 / 60.  # s
LED_SWITCH_TIME = 0.5  # s
# sats lower than the first entry will be displayed in the lowest ring,
# those between the first and second in the second ring, and so on
UPPER_LEVELS_ALT_LOWER_BOUNDARIES = [500, 1000, 2500]
# --------------------------------------------------------------


# TLE constants
SPACETRACK_URL = ("https://www.space-track.org/ajaxauth/login -d"
                  "'identity={}&password={}"
                  "&query=https://www.space-track.org/basicspacedata/query/"
                  "class/tle_latest/ORDINAL/1/EPOCH/%3Enow-30/orderby/NORAD_CAT_ID/format/3le'"
                  ).format(SPACETRACK_USER, SPACETRACK_PASSWD)
TLE_FILENAME = "3le.txt"
# --------------------------------------------------------------


# Satellite categorization constants

# - if multiple sats would be displayed on the same led the one with the higher
#   priority wins
#
# - tft shows colors a bit differently than leds, so define separate
#   satellite names
#
# - Satellite names are compared against all the substrings in order.
#   If one matches the satellite is in that class.

HIGHLY_INTERESTING_CLASS = ["ISS", "TIANGONG", "DRAGON", "SOYUZ", "PROGRESS", "HST", "CYGNUS", "GP-B", "TINTIN"]
PLANETLABS_CLASS = ["FLOCK", "DOVE"]

CLASS_COLORS_PRIORITIES = [  # [substring, substring,...]: (tft_color, priority, led_color)
    (["DEB"], (RGB(255, 0, 0), 0, RGB(255, 0, 0))),
    (["R/B"], (RGB(255, 90, 0), 1, RGB(188, 86, 0))),
    (PLANETLABS_CLASS, (RGB(0, 0, 255), 2, RGB(0, 0, 255))),
    (HIGHLY_INTERESTING_CLASS, (RGB(0, 255, 0), 10, RGB(0, 255, 0))),
    ([""], (RGB(255, 255, 255), 2, RGB(255 // 3, 255 // 3, 255 // 3))),  # wildcard
]
# --------------------------------------------------------------


# constants describing the arrangement of the LEDs
RING_RADII = [47.5, 32.0, 16.5, 0.0]
RING_LEDNS = [18, 12, 6, 1]
RING_STARTANGLES = [-np.pi / 2 + np.deg2rad(10), -np.pi / 2, -np.pi / 2 - np.deg2rad(30), 0]
RING_DIRECTIONS = [1, -1, -1, 1]  # I connected the LEDs in the first ring in the opposite direction for some reason...
# --------------------------------------------------------------

# constants related to the WS2812B LEDs
LED_COUNT = 37 * 4  # Number of LED pixels.
LED_PIN = 18  # GPIO pin connected to the pixels (18 uses PWM!).
# LED_PIN        = 10      # GPIO pin connected to the pixels (10 uses SPI /dev/spidev0.0).
LED_FREQ_HZ = 800000  # LED signal frequency in hertz (usually 800khz)
LED_DMA = 11  # DMA channel to use for generating signal (try 10)
LED_BRIGHTNESS = 50  # Set to 0 for darkest and 255 for brightest
LED_INVERT = False  # True to invert the signal (when using NPN transistor level shift)
LED_CHANNEL = 0  # set to '1' for GPIOs 13, 19, 41, 45 or 53
# --------------------------------------------------------------


# constants related to the spi tft display
# Don't forget the other 2 SPI pins SCK and MOSI (SDA)
TFT_RST = 23
TFT_CE = 0  # 0 or 1 for CE0 / CE1 number (NOT the pin#)
TFT_DC = 22  # Labeled on board as "A0"
TFT_LED = 24  # LED backlight sinks 10-14 mA @ 3V
# --------------------------------------------------------------

# calculated constants for demo.py
def ring_led_indices():
    led_index = 0
    indices = []
    for nleds, direction in zip(RING_LEDNS, RING_DIRECTIONS):
        indices.append(list(range(led_index, led_index + nleds)))
        if direction == 1:
            indices[-1].reverse()
        led_index += nleds
    indices.reverse()
    return indices


RING_LED_INDICES = ring_led_indices()
LEVEL_LEDN = sum(RING_LEDNS)
# --------------------------------------------------------------

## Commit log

2018-09-30 performance improvement??
    didn't really make much difference
    [main.py, orbit_np.py]
2018-09-30 fixed loop when updating tle
    [main.py]
2018-10-01 don't recalculate led step size when getting same config again
    this would cause the step size to be halved if the next update came in before the switch was complete
2018-10-02 fixed direction of spinning animation, reverted loading message
    [demo.py, main.py]
2018-10-10 fix displaying satellite names after showing message
    [main.py]
2018-10-20 added stl files for 3d printed part and LED PCB files
    [Button.stl, bottom.stl, bottom_pillar.stl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]
2018-10-20 added BOM
    [BOM.csv]
2018-10-22 tweaked led arrangement to fit better with actual pcb
2018-10-25 some more types, corrected number of text lines on display
    [main.py]
2018-10-25 reversed VCC/GND connections of LED PCB to simplify assembly
    [main.brd, main.sch]
2018-10-25 corrected silkscreen label for LED PCB connections
    [main.brd]
2018-11-03 added auxiliary PCBs
    [auxiliary.brd, auxiliary.sch]
2018-11-03 updated 3d printed part for new aux PCBs
    Note that these are for a slightly earlier version of the PCBs so e.g. the display cutout might not fit exactly.
    [Button.stl, interface plate.stl]
2018-11-03 adjusted cutout for usb power cord
    [case.stl]
2018-11-04 added picture and explanations of aux PCBs
    [BOM.csv, main.brd, main.sch]
2018-11-04 added comment about button functions
2018-11-12 uncompressed gerbers
    [auxiliary.GBL, auxiliary.GBO, auxiliary.GBP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]
2018-11-12 ignore gerber files for github language detection
2020-04-13 changed size of capacitors from 0401 to 0805
    (schematic not updated yet...)
    [LED_PCB.GBL, LED_PCB.GBO, LED_PCB.GBP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]
2020-04-13 updated bom and schematic
    [BOM.csv, main.sch]
2020-04-17 moved component designators to avoid overlaps
    [LED_PCB.GBO]
